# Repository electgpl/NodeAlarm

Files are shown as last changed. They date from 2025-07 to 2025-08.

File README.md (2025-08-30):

# 🔔 Wireless Alarm Sensor with ESP32-C3 + RFM69 + PIR (AS312)

This project consists of an ultra-low-power wireless motion sensor based on an **ESP32-C3**, an **RFM69 transceiver** in the 926 MHz FSK band, and an **AS312 PIR sensor** as the main detector.

Designed with an **Open Source Hardware** philosophy, powered by a **3V CR123 cell**, and aimed at low-power, long-life security, monitoring, and home automation applications.

---

## 📸 Top View of the PCB

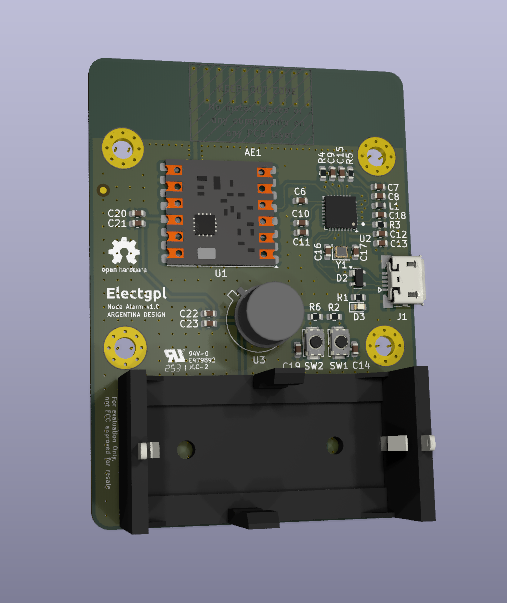
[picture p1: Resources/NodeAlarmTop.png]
NodeAlarm PCB Top View


---

## 📡 Specs

- **MCU:** ESP32-C3 (RISC-V, Wi-Fi, BLE)
- **Transceiver:** RFM69 (FSK, 926 MHz, point-to-point or custom network)
- **Sensor PIR:** AS312 (interrupt mode, ultra-low power consumption)
- **Low power mode:** DeepSleep, waking up by IRQ
- **Standby consumption:** < 30 µA
- **Power supply:** 3V CR123 battery
- **Manufacturing PCBA:** NextPCB
- **Open Hardware:** License CERN-OHL v2
- **Firmware:** PlatformIO / Arduino Framework

---

## 🔋 Estimated consumption

| State | Typical consumption |
|---|---|
| DeepSleep | ~24 µA |
| PIR & CORE |  ~9 mA by 5s |
| TX RFM69 | ~18 mA by 1.5s |

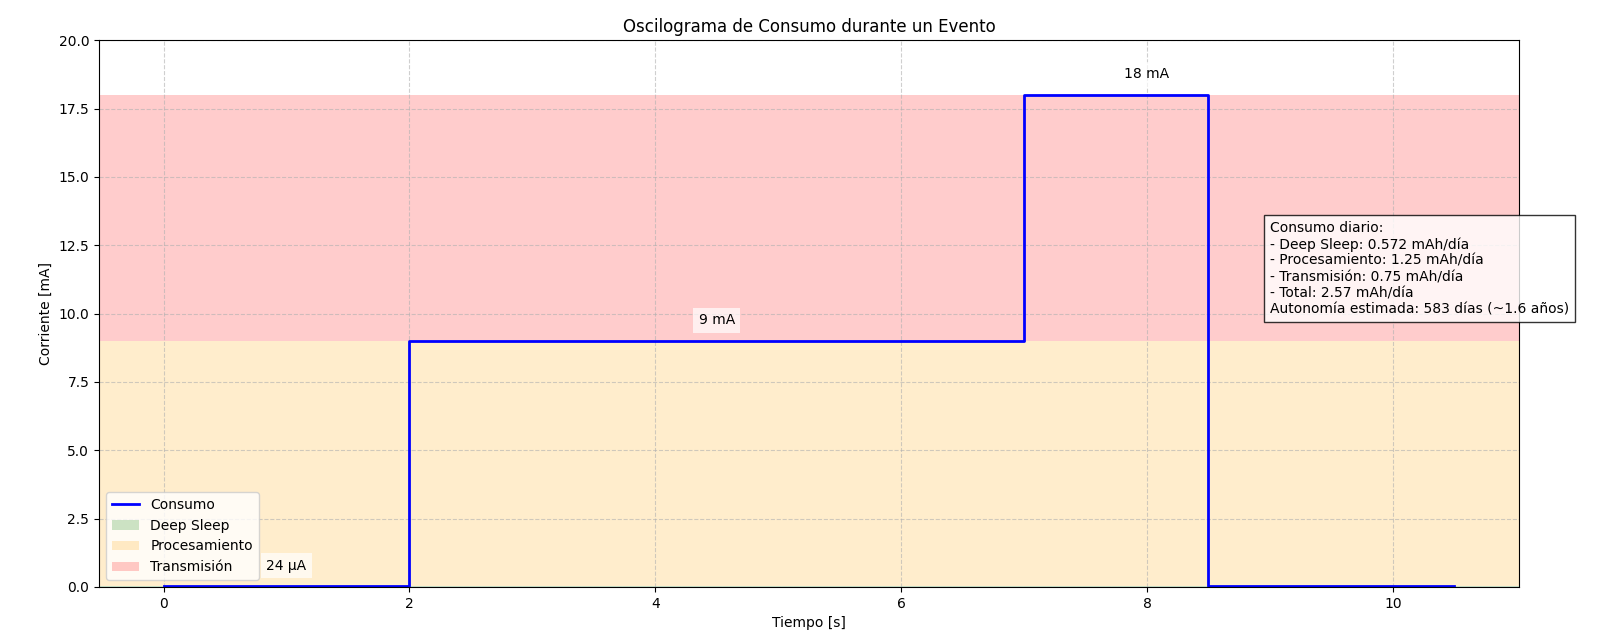
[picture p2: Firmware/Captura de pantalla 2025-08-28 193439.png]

---

This repository is released under a dual-license model:

---

## 📐 Hardware (KiCad designs)

**License:** [CERN Open Hardware License v2](https://ohwr.org/project/cernohl/wikis/home)

You are free to use, study, modify and distribute the hardware files, provided that:
- Derivative works are also released under CERN-OHL v2.
- Modifications are documented.
- Attribution is preserved.

---

## 💻 Firmware (source code under `/firmware/`)

**License:** MIT License

```text
MIT License

Copyright (c) 2025 Electgpl

Permission is hereby granted, free of charge, to any person obtaining a copy
of this software and associated documentation files (the “Software”), to deal
in the Software without restriction, including without limitation the rights to
use, copy, modify, merge, publish, distribute, sublicense, and/or sell copies
of the Software, and to permit persons to whom the Software is furnished to do
so, subject to the following conditions.

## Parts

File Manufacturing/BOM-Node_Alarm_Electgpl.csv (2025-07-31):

MPN | Qty | Designator | value | manufacturer | Category | SKU | Customer Supply | Customer Remark
 | 1 | AE1 | Antenna
 | 1 | BT1 | BH-123A-A1CJ002
 | 18 | C10,C11,C9,C15,C6,C14,C22,C19,C12,C8,C16,C21,C7,C23,C20,C17,C18,C13 | 1u
 | 1 | D2 | SP0503BAHTG
 | 1 | D3 | LED
 | 2 | FID1,FID2 | Fiducial
 | 4 | H4,H3,H2,H1 | MountingHole_Pad
 | 1 | J1 | U254-051T-4BH83-F1S
 | 1 | L1 | 2nH
 | 6 | R3,R6,R5,R4,R2,R1 | 50R
 | 2 | SW1,SW2 | SW_Push
 | 5 | TP2,TP5,TP3,TP4,TP1 | TestPoint
 | 1 | U1 | RFM69HCW
 | 1 | U2 | ESP32-C3FH4
 | 1 | U3 | AS312
 | 1 | Y1 | R940000096

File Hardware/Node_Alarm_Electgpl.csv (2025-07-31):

Reference | Qty | Value | DNP | Footprint | LCSC | MFN
AE1 | 1 | Antenna | DNP | xresource_kicadlibrary:Texas_SWRA416_868MHz_915MHz
BT1 | 1 | BH-123A-A1CJ002 |  | Battery:BatteryHolder_Bulgin_BX0123_1xCR123 | C5290177 | BH-123A-A1CJ002
C1,C10,C15,C18 | 4 | 1u |  | Capacitor_SMD:C_0603_1608Metric | C1592 | CL10A105KO8NNNC
C2,C5 | 2 | 47u |  | Capacitor_SMD:C_0603_1608Metric | C140782 | GRM188R60J476ME15D
C3,C4,C6,C8,C9,C11,C12,C20,C22 | 9 | 100n |  | Capacitor_SMD:C_0603_1608Metric | C14663 | CC0603KRX7R9BB104
C7,C13,C14,C19,C21,C23 | 6 | 10u |  | Capacitor_SMD:C_0603_1608Metric | C85713 | CL10A106MP8NNNC
C16,C17 | 2 | 10p |  | Capacitor_SMD:C_0603_1608Metric | C106245 | CC0603JRNPO9BN100
D1,D4 | 2 | DS310W |  | Diode_SMD:D_SOD-123F | C123902 | DS310W
D2 | 1 | SP0503BAHTG |  | Package_TO_SOT_SMD:SOT-143 | C7074 | SP0503BAHTG
D3 | 1 | LED |  | LED_SMD:LED_0603_1608Metric | C965799 | XL-1608SURC-06
F1 | 1 | nSMD150 |  | Fuse:Fuse_1206_3216Metric_Pad1.42x1.75mm_HandSolder | C70084 | nSMD150-13.2V
FID1,FID2 | 2 | Fiducial | DNP | Fiducial:Fiducial_1mm_Mask2mm
H1,H2,H3,H4 | 4 | MountingHole_Pad | DNP | MountingHole:MountingHole_3.2mm_M3_Pad_Via
J1 | 1 | U254-051T-4BH83-F1S |  | Connector_USB:USB_Micro-B_XKB_U254-051T-4BH83-F1S | C397452 | U254-051T-4BH83-F1S
JMP1 | 1 | 0R |  | Resistor_SMD:R_0603_1608Metric | C1512169 | RC0603JR-130RL
L1 | 1 | 2nH |  | Inductor_SMD:L_0603_1608Metric | C395081 | VHF160808H2N0ST
PFB1 | 1 | 600R |  | Capacitor_SMD:C_0603_1608Metric | C356971 | HCB1608KF-300T50
R1,R2,R4,R5,R6 | 5 | 10k |  | Resistor_SMD:R_0603_1608Metric | C98220 | RC0603FR-0710KL
R3 | 1 | 50R |  | Resistor_SMD:R_0603_1608Metric | C849792 | RT0603BRE0750RL
SW1,SW2 | 2 | SW_Push |  | Button_Switch_SMD:SW_Push_SPST_NO_Alps_SKRK | C115357 | SKRKAEE020
TP1,TP2,TP3,TP4,TP5 | 5 | TestPoint | DNP | TestPoint:TestPoint_Pad_D2.0mm
U1 | 1 | RFM69HCW |  | RF_Module:HOPERF_RFM9XW_SMD | ? | DL-RFM69HCW-915M
U2 | 1 | ESP32-C3FH4 |  | Package_DFN_QFN:QFN-32-1EP_5x5mm_P0.5mm_EP3.7x3.7mm | C2858491 | ESP32-C3FH4
U3 | 1 | AS312 |  | Package_TO_SOT_THT:TO-39-3 | C90465 | AS312
U4 | 1 | MCP1826S-3302E/DB |  | Package_TO_SOT_SMD:SOT-223 | C638624 | MCP1826S-3302E/DB
Y1 | 1 | R940000096 |  | Crystal:Crystal_SMD_2016-4Pin_2.0x1.6mm | C7206306 | R940000096

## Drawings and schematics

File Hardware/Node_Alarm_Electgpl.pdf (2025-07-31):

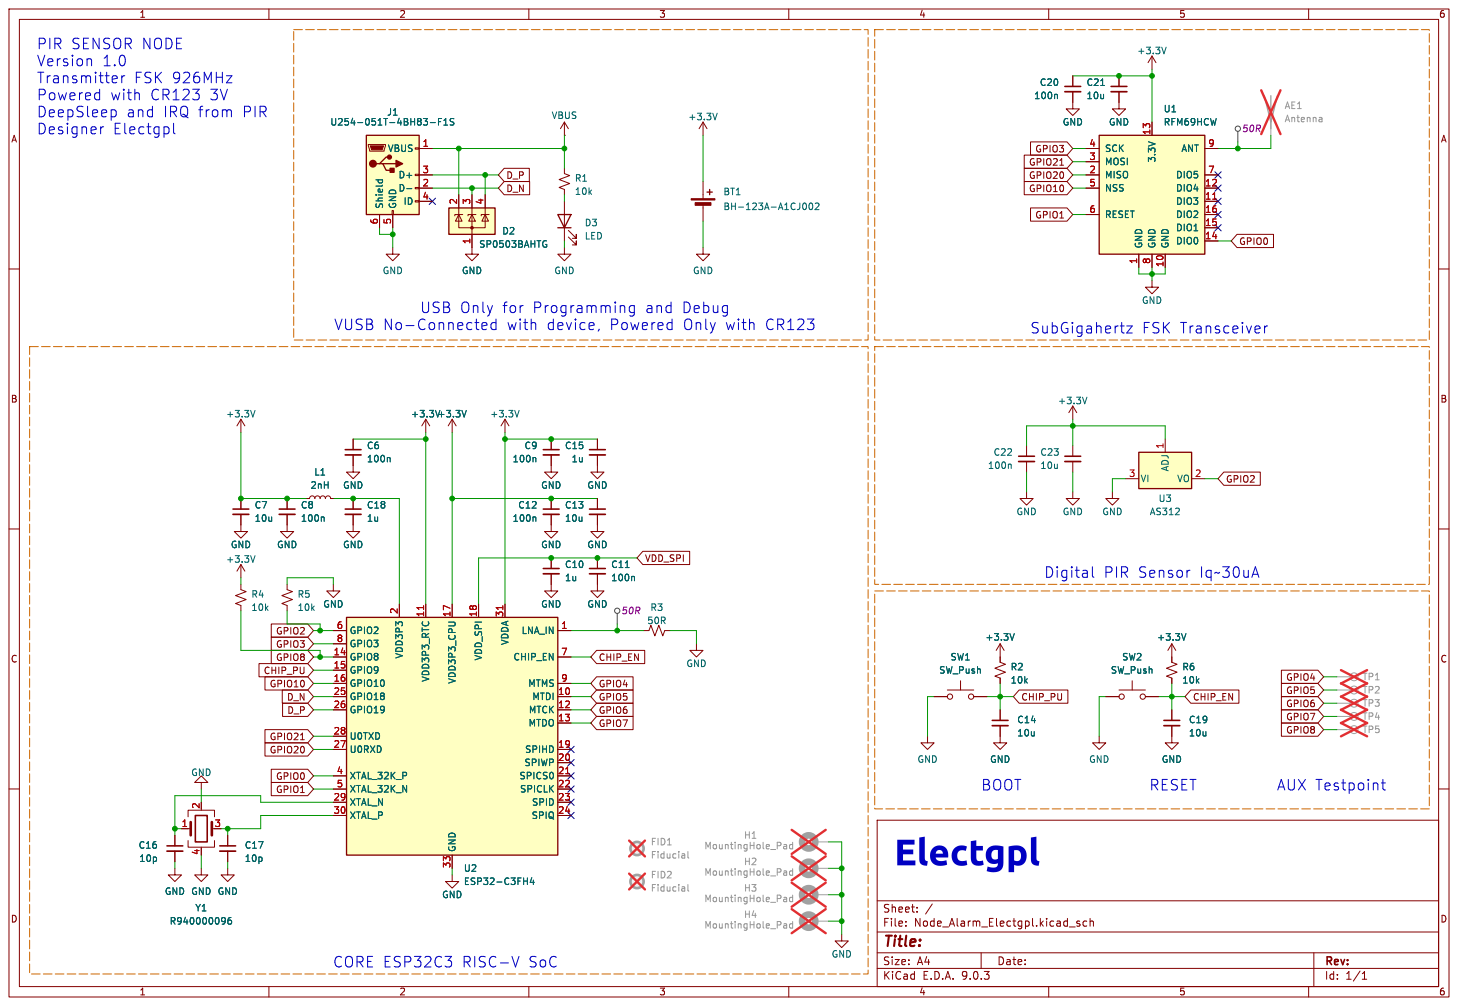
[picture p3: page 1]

PIR SENSOR NODE
Version 1.0
Powered with CR123 3V
DeepSleep and IRQ from PIR
Designer Electgpl

Digital PIR Sensor Iq~30uA

Id: 1/1 Title: File: Node_Alarm_Electgpl.kicad_sch Sheet: /

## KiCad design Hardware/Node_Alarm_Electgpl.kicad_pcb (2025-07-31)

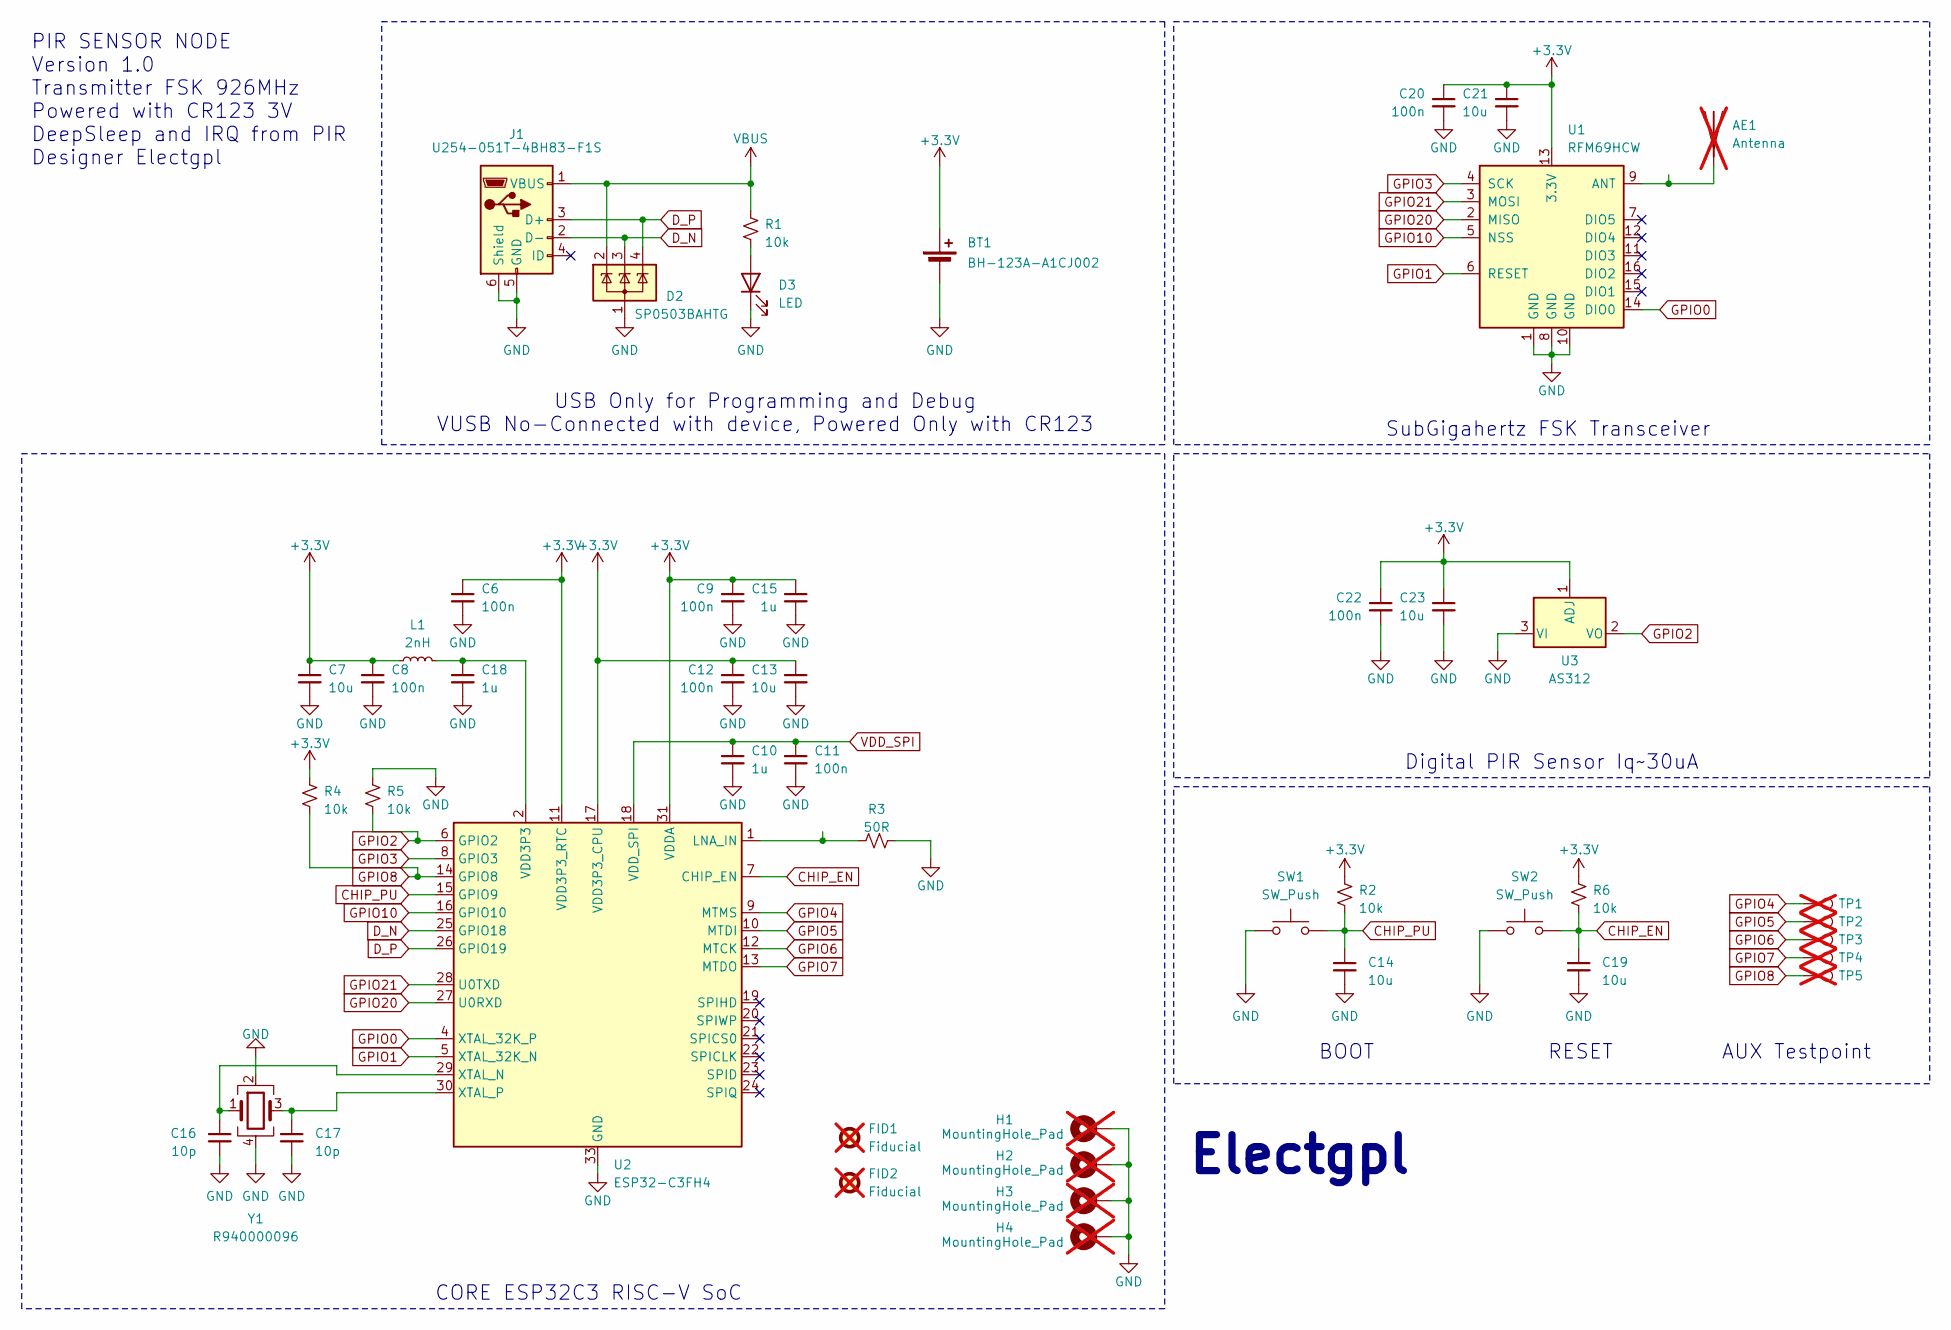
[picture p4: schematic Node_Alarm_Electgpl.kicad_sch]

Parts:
AE1: Antenna; Texas_SWRA416_868MHz_915MHz; not fitted
BT1: BH-123A-A1CJ002; BatteryHolder_Bulgin_BX0123_1xCR123; LCSC C5290177
C6, C8, C9, C11, C12, C20, C22: 100n; C_0603_1608Metric; MFR P/N CC0402KRX7R9BB104; LCSC C14663
C7, C13, C14, C19, C21, C23: 10u; C_0603_1608Metric; MFR P/N GCM188D70J106ME36D; LCSC C85713
C10, C15, C18: 1u; C_0603_1608Metric; MFR P/N CL05X105KP5NNNC; LCSC C1592
C16, C17: 10p; C_0603_1608Metric; MFR P/N GRM1555C1H100GA01D; LCSC C106245
D2: SP0503BAHTG; SOT-143; MFR P/N SP0503BAHTG; LCSC C7074
D3: LED; LED_0603_1608Metric; MFR P/N TJ-S1608B06HQYJY-A3; LCSC C965799
FID1, FID2: Fiducial; Fiducial_1mm_Mask2mm; not fitted
H1, H2, H3, H4: MountingHole_Pad; MountingHole_3.2mm_M3_Pad_Via; not fitted
J1: U254-051T-4BH83-F1S; USB_Micro-B_XKB_U254-051T-4BH83-F1S; MFR P/N U254-051T-4BH83-F1S; LCSC C397452
L1: 2nH; L_0603_1608Metric; LCSC C395081
R1, R2, R4, R5, R6: 10k; R_0603_1608Metric; MFR P/N RC0402JR-0710KL; LCSC C98220
R3: 50R; R_0603_1608Metric; MFR P/N RT0603BRE0750RL; LCSC C849792
SW1, SW2: SW_Push; SW_Push_SPST_NO_Alps_SKRK; MFR P/N SKRKAEE020; LCSC C115357
TP1, TP2, TP3, TP4, TP5: TestPoint; TestPoint_Pad_D2.0mm; not fitted
U1: RFM69HCW; HOPERF_RFM9XW_SMD; LCSC ?
U2: ESP32-C3FH4; QFN-32-1EP_5x5mm_P0.5mm_EP3.7x3.7mm; LCSC C2858491
U3: AS312; TO-39-3; LCSC C90465
Y1: R940000096; Crystal_SMD_2016-4Pin_2.0x1.6mm; MFR P/N TAXM40M4ZHBCDT2T; LCSC C7206306

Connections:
+3.3V: BT1.1 (+), C6.1, C7.1, C8.1, C9.1, C12.1, C13.1, C15.1, C20.1, C21.1, C22.1, C23.1, L1.1, R2.1, R4.1, R6.1, U1.13 (3.3V), U2.11 (VDD3P3_RTC), U2.17 (VDD3P3_CPU), U2.31 (VDDA), U2.32 (VDDA), U3.1 (ADJ)
CHIP_EN: C19.1, R6.2, SW2.2, U2.7 (CHIP_EN)
CHIP_PU: C14.1, R2.2, SW1.2, U2.15 (GPIO9)
D_N: D2.3 (K), J1.2 (D-), U2.25 (GPIO18)
D_P: D2.4 (K), J1.3 (D+), U2.26 (GPIO19)
GND: BT1.2 (-), C6.2, C7.2, C8.2, C9.2, C10.2, C11.2, C12.2, C13.2, C14.2, C15.2, C16.2, C17.2, C18.2, C19.2, C20.2, C21.2, C22.2, C23.2, D2.1 (A), D3.1 (K), H1.1, H2.1, H3.1, H4.1, J1.5 (GND), J1.6 (Shield), R3.2, R5.1, SW1.1, SW2.1, U1.1 (GND), U1.8 (GND), U1.10 (GND), U2.33 (GND), U3.3 (VI), Y1.2, Y1.4
GPIO0: U1.14 (DIO0), U2.4 (XTAL_32K_P)
GPIO1: U1.6 (RESET), U2.5 (XTAL_32K_N)
GPIO2: R5.2, U2.6 (GPIO2), U3.2 (VO)
GPIO3: U1.4 (SCK), U2.8 (GPIO3)
GPIO4: TP1.1, U2.9 (MTMS)
GPIO5: TP2.1, U2.10 (MTDI)
GPIO6: TP3.1, U2.12 (MTCK)
GPIO7: TP4.1, U2.13 (MTDO)
GPIO8: R4.2, TP5.1, U2.14 (GPIO8)
GPIO10: U1.5 (NSS), U2.16 (GPIO10)
GPIO20: U1.2 (MISO), U2.27 (U0RXD)
GPIO21: U1.3 (MOSI), U2.28 (U0TXD)
unnamed: AE1.1 (A), U1.9 (ANT)
unnamed: C18.1, L1.2, U2.2 (VDD3P3), U2.3 (VDD3P3)
unnamed: D3.2 (A), R1.2
unnamed: R3.1, U2.1 (LNA_IN)
unnamed: C16.1, U2.29 (XTAL_N), Y1.1
unnamed: C17.1, U2.30 (XTAL_P), Y1.3
VBUS: D2.2 (K), J1.1 (VBUS), R1.1
VDD_SPI: C10.1, C11.1, U2.18 (VDD_SPI)

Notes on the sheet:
AUX Testpoint
Electgpl
CORE ESP32C3 RISC-V SoC
USB Only for Programming and Debug VUSB No-Connected with device, Powered Only with CR123
PIR SENSOR NODE Version 1.0 Transmitter FSK 926MHz Powered with CR123 3V DeepSleep and IRQ from PIR Designer Electgpl
BOOT
Digital PIR Sensor Iq~30uA
SubGigahertz FSK Transceiver
RESET

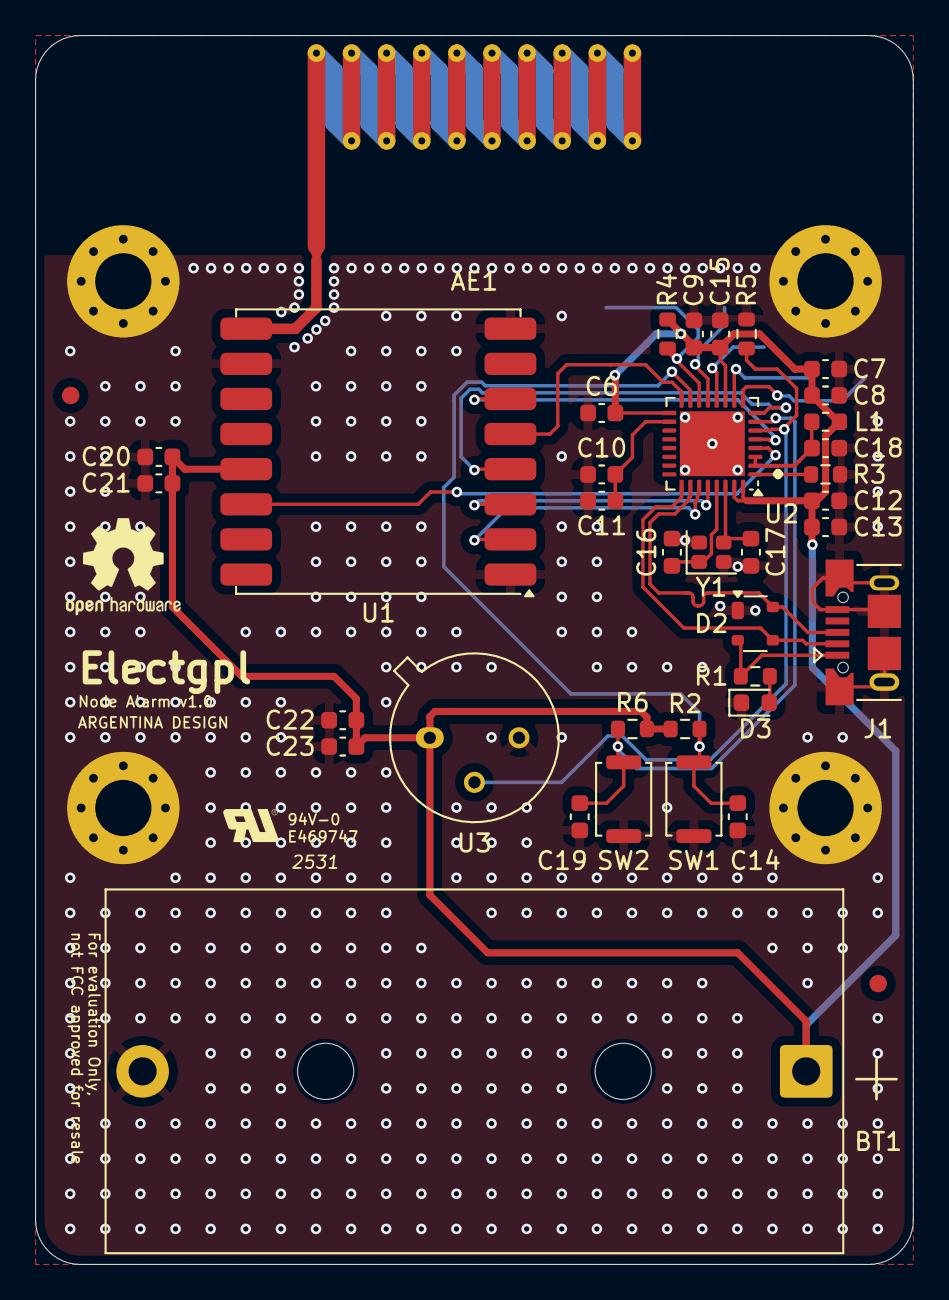
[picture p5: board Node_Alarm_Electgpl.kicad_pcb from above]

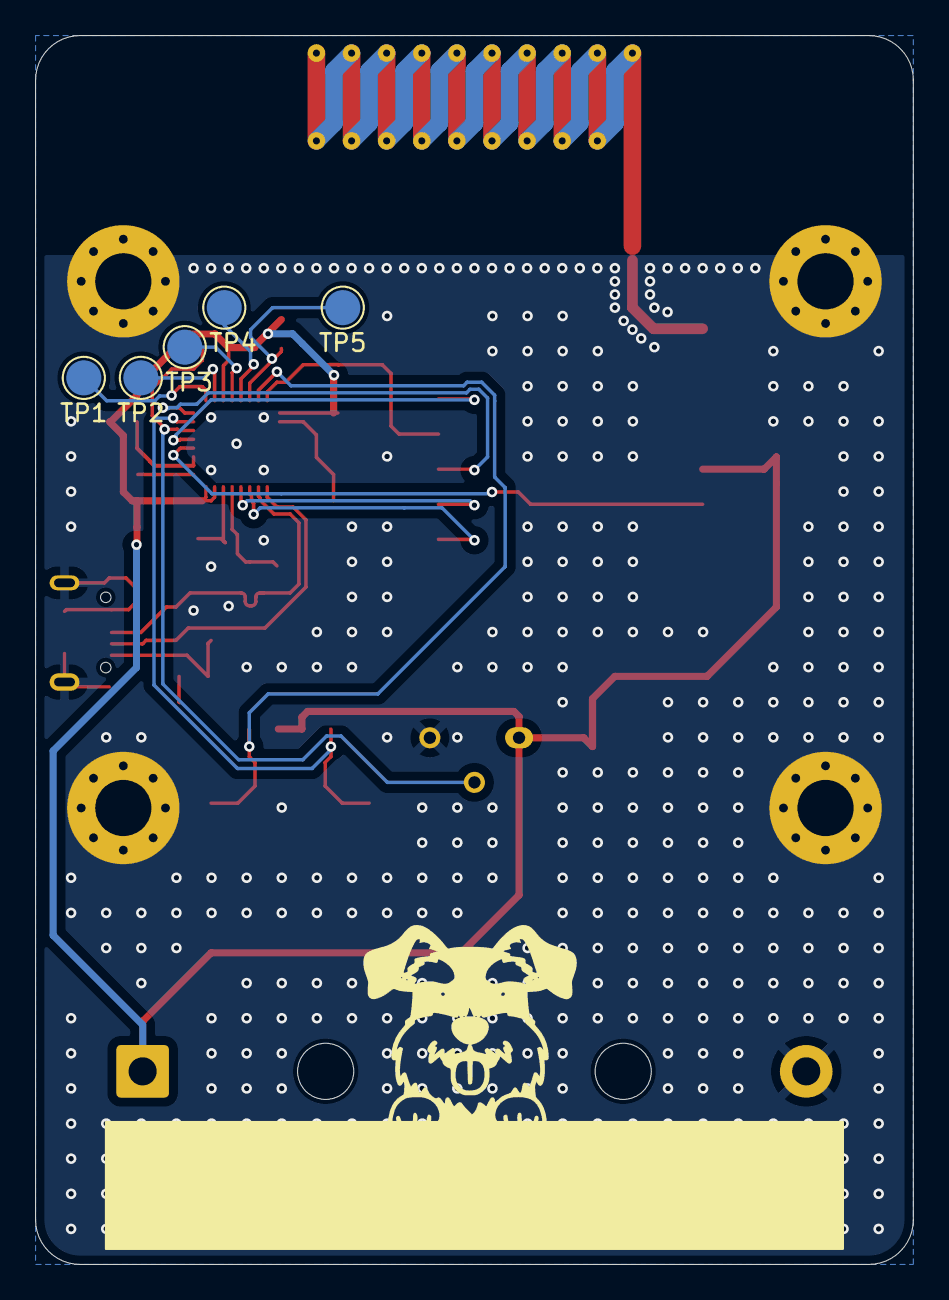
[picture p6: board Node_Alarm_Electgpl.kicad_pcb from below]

Board: 2 copper layers, 50.0 x 70.0 mm, 47 parts (5 on the bottom side), 26 nets.

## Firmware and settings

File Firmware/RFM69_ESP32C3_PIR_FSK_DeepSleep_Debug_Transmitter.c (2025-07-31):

#include <SPI.h>
#include <RH_RF69.h>
#include "esp_sleep.h"
#include "driver/gpio.h"

#define RFM69_SCK   3
#define RFM69_MISO  20
#define RFM69_MOSI  21
#define RFM69_CS    10
#define RFM69_IRQ   0
#define RFM69_RST   1
#define RF69_FREQ 915.0
#define PIR_PIN 2       // Pin digital del PIR (GPIO2)
#define PIR_ID 1        // ID del sensor PIR (ej: 1 para "P1")

// Configuración de deep sleep
#define SLEEP_TIME_US 30000000  // 30 segundos en microsegundos (opcional, como backup)

RH_RF69 rf69(RFM69_CS, RFM69_IRQ);

void setup() {
  Serial.begin(115200);
  delay(2000); // Dar tiempo para que se abra el monitor serie
  
  Serial.println("=== INICIANDO SISTEMA PIR ===");
  Serial.flush();
  
  // Verificar causa del despertar
  esp_sleep_wakeup_cause_t wakeup_reason = esp_sleep_get_wakeup_cause();
  
  Serial.print("Causa del despertar: ");
  switch(wakeup_reason) {
    case ESP_SLEEP_WAKEUP_GPIO: 
      Serial.println("PIR - Movimiento detectado"); 
      break;
    case ESP_SLEEP_WAKEUP_TIMER: 
      Serial.println("Timer"); 
      break;
    default: 
      Serial.println("Power ON o Reset"); 
      break;
  }
  Serial.flush();
  
  // Inicializar RFM69
  Serial.println("Paso 1: Inicializando RFM69...");
  Serial.flush();
  initializeRFM69();
  Serial.println("RFM69 inicializado correctamente");
  Serial.flush();
  
  // Configurar GPIO2 como entrada - usar pinMode como en tu código que funciona
  Serial.println("Paso 2: Configurando GPIO2...");
  Serial.flush();
  
  pinMode(PIR_PIN, INPUT);
  delay(500); // Dar tiempo para que se estabilice
  
  // Leer estado actual del PIR varias veces
  Serial.println("Leyendo PIR múltiples veces:");
  for(int i = 0; i < 5; i++) {
    int pirState = digitalRead(PIR_PIN);
    Serial.print("  Lectura ");
    Serial.print(i+1);
    Serial.print(": ");
    Serial.println(pirState);
    delay(200);
  }
  
  int pirState = digitalRead(PIR_PIN);
  Serial.print("Estado PIR final: ");
  Serial.println(pirState);
  Serial.flush();
  
  // Si despertó por PIR o es power-on, enviar estado
  if (wakeup_reason == ESP_SLEEP_WAKEUP_GPIO || wakeup_reason == ESP_SLEEP_WAKEUP_UNDEFINED) {
    Serial.println("Paso 3: Enviando estado PIR...");
    Serial.flush();
    sendPIRState(pirState);
  }
  
  // Para debug: mostrar qué GPIOs causaron el wake-up
  if (wakeup_reason == ESP_SLEEP_WAKEUP_GPIO) {
    uint64_t gpio_wakeup_status = esp_sleep_get_gpio_wakeup_status();
    Serial.print("GPIO que causó wake-up: ");
    Serial.println(gpio_wakeup_status, BIN);
    Serial.flush();
  }
  
  // Habilitar wake-up por GPIO2 - probar con flanco ascendente en lugar de nivel
  Serial.println("Paso 4: Configurando wake-up...");
  Serial.flush();
  
  esp_sleep_enable_gpio_wakeup();
  gpio_wakeup_enable(GPIO_NUM_2, GPIO_INTR_POSEDGE); // Cambiar a flanco ascendente
  
  Serial.print("GPIO2 configurado para wake-up. Estado antes de sleep: ");
  Serial.println(gpio_get_level(GPIO_NUM_2));
  Serial.flush();
  
  // Opcional: Timer de backup para despertar cada 30 segundos
  // esp_sleep_enable_timer_wakeup(SLEEP_TIME_US);
  
  // Poner RFM69 en sleep antes del deep sleep del ESP32
  putRFM69ToSleep();
  
  // TEMPORAL: Para debug, usar modo normal en lugar de deep sleep
  // Comentar las siguientes 3 líneas para activar deep sleep
  Serial.println("ACTIVANDO MODO DEBUG - SIN DEEP SLEEP");
  Serial.flush();
  debugMode(); // Función de debug - REMOVER después
  return; // No llegar al deep sleep
  
  /*
  Serial.println("Entrando en deep sleep...");
  Serial.flush(); // Asegurar que se envíe todo por serial
  delay(100);
  
  // Entrar en deep sleep
  esp_deep_sleep_start();
  */
}

void loop() {
  // Este loop nunca se ejecutará debido al deep sleep
  // Todo el procesamiento se hace en setup()
}

void initializeRFM69() {
  SPI.begin(RFM69_SCK, RFM69_MISO, RFM69_MOSI);
  
  // Reset del RFM69
  pinMode(RFM69_RST, OUTPUT);
  digitalWrite(RFM69_RST, LOW);
  delay(100);
  digitalWrite(RFM69_RST, HIGH);
  delay(100);
  digitalWrite(RFM69_RST, LOW);
  delay(100);
  
  Serial.println("Inicializando RFM69...");
  if (!rf69.init()) {
    Serial.println("Fallo al inicializar RFM69");
    // En lugar de while(1), mejor reiniciar
    ESP.restart();
  }
  
  // Verificar comunicación SPI
  uint8_t version = rf69.spiRead(0x10);
  Serial.print("RegVersion (0x10) = 0x");
  Serial.println(version, HEX);
  
  if (version != 0x24) {
    Serial.println("Error en comunicación SPI");
    ESP.restart();
  }
  
  // Configurar frecuencia y potencia
  if (!rf69.setFrequency(RF69_FREQ)) {
    Serial.println("Fallo al configurar frecuencia");
    ESP.restart();
  }
  
  rf69.setTxPower(20, true);
  rf69.spiWrite(0x02, 0x00); // Configuración adicional si es necesaria
}

void sendPIRState(int state) {
  char message[8];
  snprintf(message, sizeof(message), "P%d,%d", PIR_ID, state);
  
  Serial.print("Enviando estado PIR: ");
  Serial.println(message);
  Serial.flush();
  
  // Usar exactamente la misma lógica que tu código que funciona
  if (rf69.send((uint8_t*)message, strlen(message))) {
    rf69.waitPacketSent();
    Serial.println("Mensaje enviado correctamente.");
  } else {
    Serial.println("ERROR: Fallo al enviar mensaje.");
  }
  
  Serial.flush();
}

void putRFM69ToSleep() {
  // Poner el RFM69 en modo sleep para minimizar consumo
  rf69.sleep();
  
  // Alternativamente, puedes usar el comando directo:
  // rf69.spiWrite(0x01, 0x00); // RegOpMode = Sleep mode
  
  Serial.println("RFM69 en modo sleep");
}

// Función de debug temporal - REMOVER después de que funcione
void debugMode() {
  Serial.println("=== MODO DEBUG - SIN DEEP SLEEP ===");
  Serial.println("Monitoreando PIR cada 2 segundos...");
  Serial.flush();
  
  int lastState = -1;
  int counter = 0;
  
  while(true) {
    counter++;
    int currentState = digitalRead(PIR_PIN); // Usar digitalRead como en tu código
    
    Serial.print("[");
    Serial.print(counter);
    Serial.print("] PIR Estado: ");
    Serial.print(currentState);
    
    if (currentState != lastState) {
      Serial.print(" -> CAMBIO DETECTADO!");
      lastState = currentState;
      Serial.println();
      Serial.flush();
      
      Serial.println("*** ENVIANDO POR CAMBIO DE ESTADO ***");
      sendPIRState(currentState);
      Serial.println("*** TRANSMISIÓN COMPLETADA ***");
      Serial.flush();
    } else {
      Serial.println(" (sin cambio)");
    }
    
    Serial.flush();
    delay(2000);
  }
}

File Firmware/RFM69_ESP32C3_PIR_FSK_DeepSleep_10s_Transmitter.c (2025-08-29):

#include <SPI.h>
#include <RH_RF69.h>
#include "esp_sleep.h"
#include "driver/gpio.h"

#define RFM69_SCK   3
#define RFM69_MISO  20
#define RFM69_MOSI  21
#define RFM69_CS    10
#define RFM69_IRQ   0
#define RFM69_RST   1
#define RF69_FREQ   915.0
#define PIR_PIN     2
#define PIR_ID      1

RH_RF69 rf69(RFM69_CS, RFM69_IRQ);

void setup() {
  esp_sleep_wakeup_cause_t wakeup_reason = esp_sleep_get_wakeup_cause();
  Serial.print("DESPERTAR: ");
  switch(wakeup_reason) {
    case ESP_SLEEP_WAKEUP_GPIO: 
      Serial.println("GPIO - PIR"); 
      break;
    case ESP_SLEEP_WAKEUP_TIMER: 
      Serial.println("TIMER"); 
      break;
    default: 
      Serial.println("POWER ON"); 
      break;
  }
  initializeRFM69();
  pinMode(PIR_PIN, INPUT);
  delay(100);
  int pirState = digitalRead(PIR_PIN);
  sendPIRState(pirState);
  setupGPIOWakeup();
  rf69.sleep();
  esp_sleep_enable_timer_wakeup(10000000);
  esp_sleep_enable_gpio_wakeup();
  int currentPIR = digitalRead(PIR_PIN);
  if (currentPIR == HIGH) {
    gpio_wakeup_enable(GPIO_NUM_2, GPIO_INTR_NEGEDGE);
  } else {
    gpio_wakeup_enable(GPIO_NUM_2, GPIO_INTR_POSEDGE);
  }
  delay(100);
  esp_light_sleep_start();
  delay(1000);
  ESP.restart();
}
void loop() {
}
void initializeRFM69() {
  SPI.begin(RFM69_SCK, RFM69_MISO, RFM69_MOSI);
  pinMode(RFM69_RST, OUTPUT);
  digitalWrite(RFM69_RST, LOW);
  delay(100);
  digitalWrite(RFM69_RST, HIGH);
  delay(100);
  digitalWrite(RFM69_RST, LOW);
  delay(100);
  if (!rf69.init()) {
    ESP.restart();
  }
  uint8_t version = rf69.spiRead(0x10);
  if (version != 0x24) {
    ESP.restart();
  }
  if (!rf69.setFrequency(RF69_FREQ)) {
    ESP.restart();
  }
  rf69.setTxPower(20, true);
  rf69.spiWrite(0x02, 0x00);
  rf69.setModeRx();
}
void sendPIRState(int state) {
  char message[8];
  snprintf(message, sizeof(message), "P%d,%d", PIR_ID, state);
  
  if (rf69.send((uint8_t*)message, strlen(message))) {
    rf69.waitPacketSent();
  }
}
void setupGPIOWakeup() {
  int currentState = digitalRead(PIR_PIN);
  esp_sleep_enable_gpio_wakeup();
  if (currentState == HIGH) {
    gpio_wakeup_enable(GPIO_NUM_2, GPIO_INTR_NEGEDGE);
  } else {
    gpio_wakeup_enable(GPIO_NUM_2, GPIO_INTR_POSEDGE);
  }
}
